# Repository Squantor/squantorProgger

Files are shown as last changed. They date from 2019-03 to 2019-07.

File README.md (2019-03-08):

# SquantProgger JTAG/SWD probe
This repository contains hardware and software for the development of the Squantprogger JTAG/SWD probe.
## What? Another programmer?
Why yes! I was not completely satisfied with the existing solutions. The two leading open source solutions like the [black magic probe](https://github.com/blacksphere/blackmagic/wiki) or the [Cortexprog](https://cortexprog.com/) have a few, in my opinion, flaws that squantProgger tries to overcome. The blackmagic probe requires a new firmware to support new devices, interface clocking is fixed speed, using the GDB interface is not entirely optimal with respect to speedups and error robustness. The Cortexprog uses bitbanged USB HID interface and is SWD only.

I really wanted to combine the strongest features of these two programmers into one package. Device support depends on the PC side software and not the probe, support SWD and JTAG at any reasonable speed (1kHz to 10MHz), be reasonably fast, no or minimal driver installation requirements.
# Repository structure
* hardware: contains the hardware of the various programmer iterations and possible extension boards
* software_embedded: contains the probe software
* software_pc: contains the PC side software
# usage
Check out using ```git clone --recurse-submodules``` as this project uses git submodules for hardware and software components.

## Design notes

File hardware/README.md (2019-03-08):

# SquantProgger hardware
There are a bunch of hardware iterations of the SquantProgger.
## SquantProgger 0.1
This programmer is the initial pilot of exploring how to create a debug probe from scratch.

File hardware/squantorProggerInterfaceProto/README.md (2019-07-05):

# Prototype for SWD/JTAG logic interface
Prototype level shifting interface for a JTAG/SWD. Operational voltage range is from 5.5V to 1.65V. The TMS switch is handled by a bus switch instead of a dual voltage level shifter. This is to prevent input/output switching on the microcontroller. This way you can more easely chain SPI transactions while using SPI chip enable pins to enable the bus
## TODO's
Still some things need to be done:
* schematic entry (Done)
* PCB layout (Done)
* Review with one night in between (Done)
* Produce at [OSHPARK](https://oshpark.com/shared_projects/nZVJTeq3) (In progress)
* Assemble (TODO)
* Test & characterise (TODO)
# BOM
Use whatever decoupling capacitors you have, most passives are predominantly 0402.
* Most 0402 capacitors for decoupling are 100nF, but 1uF is also suitable
* Series resistor R1, R2 1K can be used, the parallel caps are 22pF. These are to test if any current backflow will occur when the 1G125 is unpowered.
* U1, U2, U3 and U4 are [Diodes Incorporated 74LVC1T45DW-7 from LCSC](https://lcsc.com/product-detail/Interface-ICs_DIODES_74LVC1T45DW-7_74LVC1T45DW-7_C168855.html).
* U5 is a [Nexperia 74LVC1G125GW,125 from LCSC](https://lcsc.com/product-detail/74-Series_NXP_74LVC1G125GW_74LVC1G125GW-125_C12519.html)

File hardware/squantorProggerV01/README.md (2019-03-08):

# SquantorProgger JTAG/SWD probe version 0.1
This is the initial hardware creation of the SquantorProgger hardware to do some design exploration and figure out how to build a JTAG/SWD probe from scratch.
## Hardware architecture
The SquantProgger talks to the host system via the [CH340E](http://wch.cn/downloads/CH340DS1_PDF.html) USB to serial converter to the microcontroller [LPC824](https://www.nxp.com/products/processors-and-microcontrollers/arm-based-processors-and-mcus/lpc-cortex-m-mcus/lpc800-series-cortex-m0-plus-mcus/low-cost-microcontroll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), communication occurs at a baud rate of 1Mbaud. The CH340E also provides a reset signal via the flow control pins to reset the LPC824 and access the bootloader. The LPC824 contains the software to translate protocol calls into JTAG/SWD communication. A single output driver (74X1G125 logic chip) provides disabling of the TMS driver. The voltage level of the signals is fixed at 3.3V. The power is provided by a MCP1702 LDO. A dual P channel mosfet facilitates power switching to the target.
## HSI (Hardware Software Interface)
Description of the various connections on software programmable components.
### LPC824
### CH340E
## TODO's
Still some things need to be done:
* filling initial functions in the HSI (TODO)
* schematic entry (TODO)
* PCB layout (TODO)
* Review with one night in between (TODO)
* Produce at [OSHPARK](https://oshpark.com/) (TODO)
* Assemble (TODO)
* Test & characterise (TODO)
* update Readme.md with pictures and BOM (TODO)

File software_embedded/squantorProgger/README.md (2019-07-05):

# Squantor Programmer Probe Software
This software project contains the code for the Squantor programmer probe.
## Checking out
use ```git clone --recurse-submodules https://github.com/Squantor/squantorProgger.git``` to clone the repo and its submodules.
## Compiling
This project uses gnu make as its build system on a Linux platform. There are two build targets: release and debug. Release builds with optimizations and minimal debugging information. Debug builds with no optimization and full debug information.
```
$ make debug
$ make release
```
### Embedded targets
For debugging on embedded targets, the [Black Magic Probe](https://github.com/blacksphere/blackmagic/wiki) is used, scripts to use this debugger are present in the ```gdb_scripts``` directory. make can be used to invoke debugging:
```
make gdbusbdebug
make gdbusbrelease
```
This will build, if needed, the debug or release build respectivly and load it into the target.
```
make tpwrdisable
make tpwrenable
```
The black magic probe is capable of powering the target, these commands enable/disable this function.
### Depedencies
This program depends on a few libraries:
* [minimal LibC](https://github.com/Squantor/squantorLibC.git)
* [various embedded functions](https://github.com/Squantor/squantorLibEmbeddedC.git)
* [LPCOpen for LPC824](https://github.com/Squantor/lpc_chip_82x.git)
These are automatically checked out when using ```git clone --recurse-submodules```.
## Usage
To use the software you need the following hardware:
* [Black magic probe](https://github.com/blacksphere/blackmagic)
* $(HARDWARE)
# Hardware Software Interface (HSI)
Here is a list of signals/connections on how the probe is built up.
* Pin 12: GPIO 26: UART0 RX connection to UART TX of USB to serial converter, input
* Pin 11: GPIO 27: UART0 TX connection to UART RX of USB to serial converter, output
* Pin 13: GPIO 25: SPI0 SCK connection to JTAG TCK of the level shifter circuit, output
* Pin 14: GPIO 24: SPI0 MISO connection to JTAG TMSI of the level shifter circuit, input
* Pin 15: GPIO 15: SPI0 MOSI connection to JTAG TMSO of the level shifter circuit, output
* Pin 10: GPIO 16: SPI0 CE0 connection to JTAG TMSOE of the level shifter circuit, output
## Level shifter circuit
Descriptions of pins:
* SCK, JTAG SCK pin, level shifted via one 1T45 gate
* TMSI, input translated TMS pin, levelshifted via one 1T45 gate
* TMSO, output translated TMS pin, level shifted via 1G125
* TMSOE, output enable for the 1G125 that controls output of the TMS pin
# Additional information
If the project needs further explanation like commands, theory of operation or something else, Describe it here.
# TODO
The following tasks are still open:

* etc
# Pictures
Some pictures of a hardware project

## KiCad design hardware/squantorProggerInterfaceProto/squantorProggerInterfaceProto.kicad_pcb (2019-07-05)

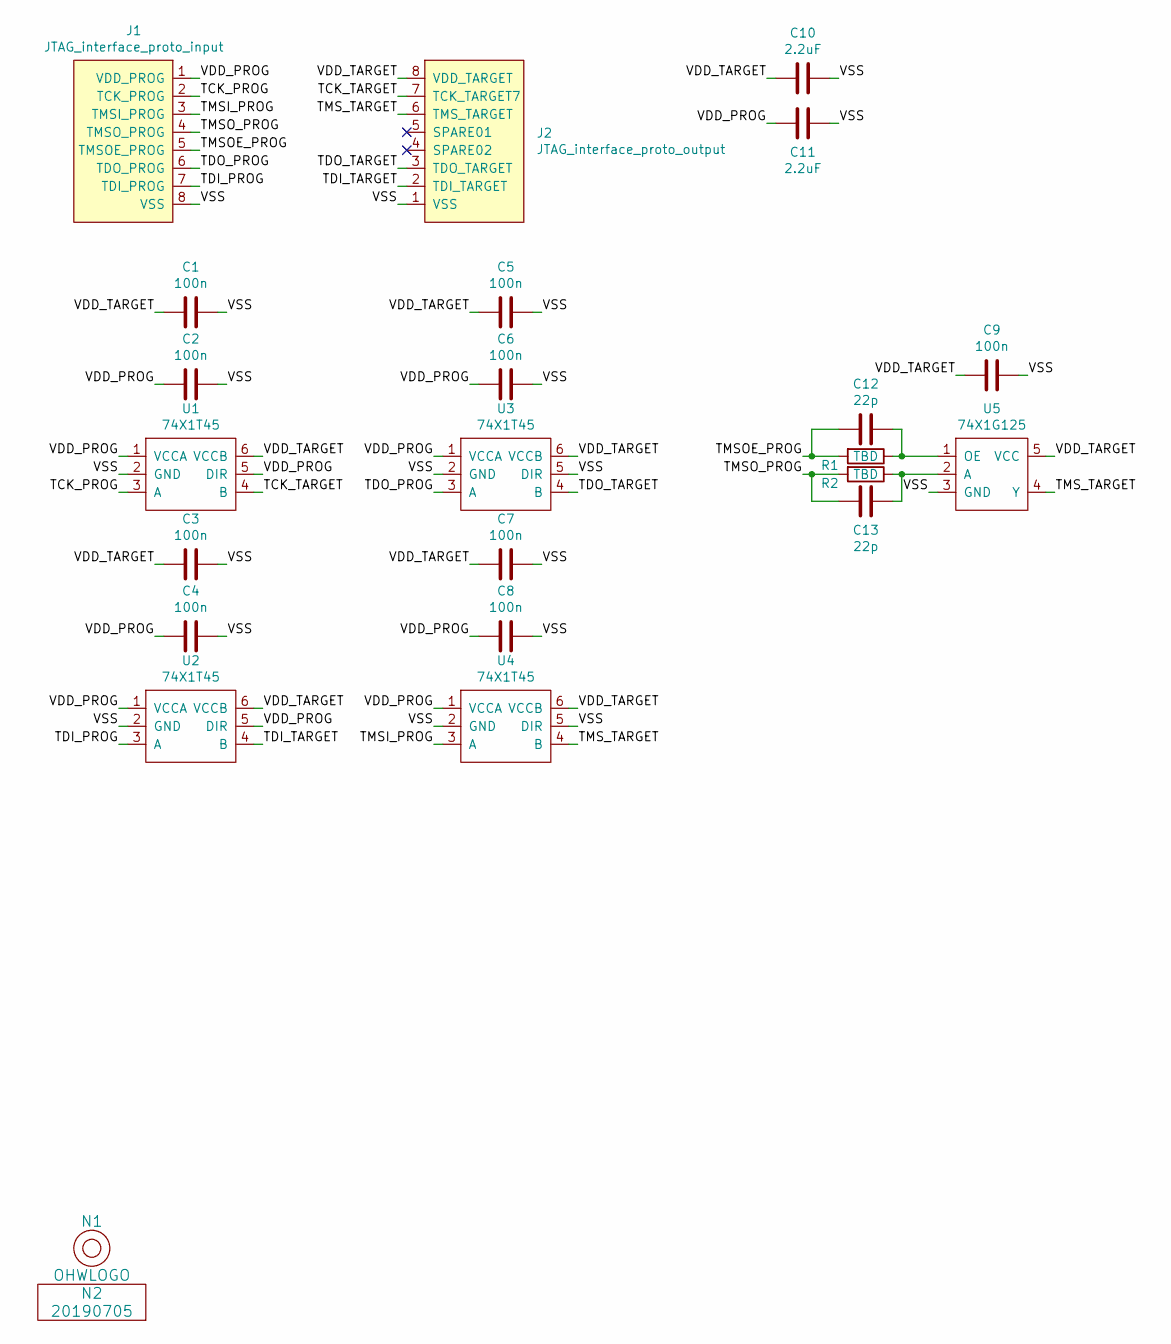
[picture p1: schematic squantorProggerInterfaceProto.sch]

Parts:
C1, C2, C3, C4, C5, C6, C7, C8, C9: 100n; C_0402
C10, C11: 2.2uF; C_0805
C12, C13: 22p; C_0402
J1: JTAG_interface_proto_input; JTAG-interface-proto-input
J2: JTAG_interface_proto_output; JTAG-interface-proto-output
N1: OHWLOGO; OSHW-Logo_5.7x6mm_SilkScreen
N2: 20190705; Label_version
R1, R2: TBD; R_0402_hand
U1, U2, U3, U4: 74X1T45; SOT363-hand
U5: 74X1G125; SOT353-hand

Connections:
/TCK_PROG: J1.2 (TCK_PROG), U1.3 (A)
/TCK_TARGET: J2.7 (TCK_TARGET7), U1.4 (B)
/TDI_PROG: J1.7 (TDI_PROG), U2.3 (A)
/TDI_TARGET: J2.2 (TDI_TARGET), U2.4 (B)
/TDO_PROG: J1.6 (TDO_PROG), U3.3 (A)
/TDO_TARGET: J2.3 (TDO_TARGET), U3.4 (B)
/TMSI_PROG: J1.3 (TMSI_PROG), U4.3 (A)
/TMSOE_PROG: C12.2, J1.5 (TMSOE_PROG), R1.2
/TMSO_PROG: C13.2, J1.4 (TMSO_PROG), R2.2
/TMS_TARGET: J2.6 (TMS_TARGET), U4.4 (B), U5.4 (Y)
/VDD_PROG: C2.2, C4.2, C6.2, C8.2, C11.2, J1.1 (VDD_PROG), U1.1 (VCCA), U1.5 (DIR), U2.1 (VCCA), U2.5 (DIR), U3.1 (VCCA), U4.1 (VCCA)
/VDD_TARGET: C1.2, C3.2, C5.2, C7.2, C9.2, C10.2, J2.8 (VDD_TARGET), U1.6 (VCCB), U2.6 (VCCB), U3.6 (VCCB), U4.6 (VCCB), U5.5 (VCC)
/VSS: C1.1, C2.1, C3.1, C4.1, C5.1, C6.1, C7.1, C8.1, C9.1, C10.1, C11.1, J1.8 (VSS), J2.1 (VSS), U1.2 (GND), U2.2 (GND), U3.2 (GND), U3.5 (DIR), U4.2 (GND), U4.5 (DIR), U5.3 (GND)
unnamed: C12.1, R1.1, U5.1 (OE)
unnamed: C13.1, R2.1, U5.2 (A)

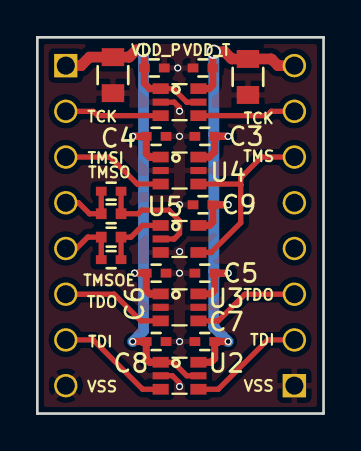
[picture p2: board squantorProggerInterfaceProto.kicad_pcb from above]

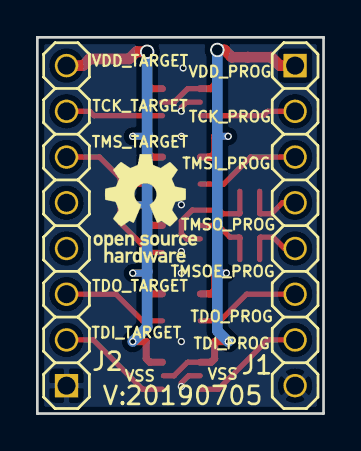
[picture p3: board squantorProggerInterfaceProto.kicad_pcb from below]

Board: 2 copper layers, 15.9 x 20.9 mm, 24 parts (4 on the bottom side), 15 nets.

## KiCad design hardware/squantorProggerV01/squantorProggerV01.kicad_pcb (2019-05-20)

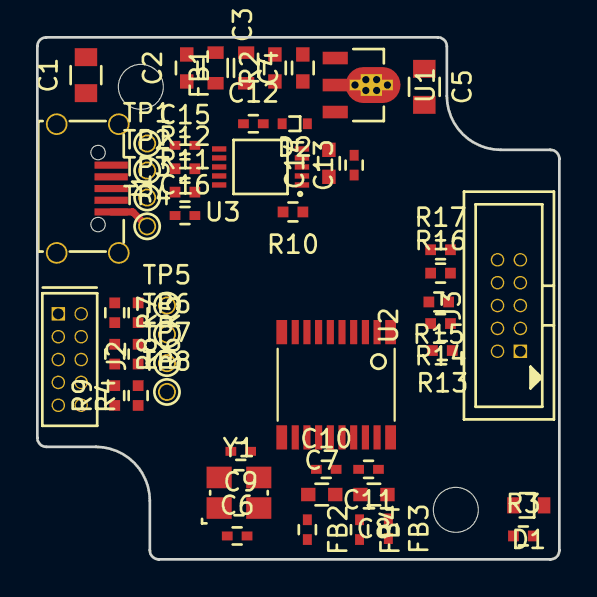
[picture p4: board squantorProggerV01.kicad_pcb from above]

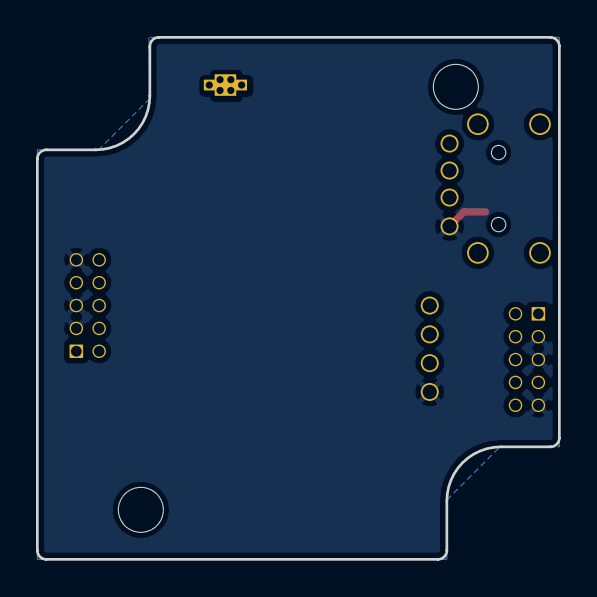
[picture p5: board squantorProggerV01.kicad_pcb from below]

Board: 2 copper layers, 29.0 x 29.0 mm, 57 parts (2 on the bottom side), 29 nets.

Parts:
C1: 100n; C_0805
C2: 100n; C_0603
C3, C4, C7, C8, C14: 1u; C_0603
C5: 10u; C_0805
C6, C9: 18p; C_0402
C10, C11, C12, C13: 100n; C_0402
C15, C16: 47p; C_0402
D1: RED; D_0603_hand
D2: D; SOD-523
FB1: 600; R_0603_hand
FB2, FB3, FB4: FB; C_0402
H1, H2: Drill_Hole_no_metal; MountingHole_2.5mm_no_metal
J1: USB-ID; USB-muB-SMD_TH
J2: JTAG_2X05; Header-0127-2X05-H006
J3: JTAG_2X05_OUT; Header-Shr-0127-2X05-H006
N1: OHWLOGO; OSHW-Symbol_6.7x6mm_SilkScreen
N2: 20190520; Label_version
R2: Fuse; R_0603_hand
R3: 1K; R_0402_hand
R4: 100K; R_0402_hand
R5, R6: 100k; R_0402_hand
R7, R8, R9, R13, R14, R15, R16, R17: 100; R_0402_hand
R10: 10K; R_0402_hand
R11, R12: 33; R_0402_hand
TP1, TP2, TP3, TP4, TP5, TP6, TP7, TP8: testpad; TestPoint_Hole_D0.8mm
U1: MCP1702-MB; SOT89-ViaTab-Microchip-MB
U2: LPC824M201JDH20; SOT360
U3: HT42B534-MSOP10; MSOP-10
Y1: 12MHz; Crystal_3225_4

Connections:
/HT42B534 application example/V33O: C14.1, U3.2
/PIO0_2: R5.2, R7.2, TP5.1, U2.8
/PIO0_3: R6.2, R8.2, TP6.1, U2.7
/PIO0_8: C9.1, U2.14, Y1.3
/PIO0_9: C6.1, U2.13, Y1.1
/RESET: R4.2, R9.2, TP7.1, U2.5
/TXO: R10.1, U3.5
/USB_D+: J1.3, R11.1, TP3.1
/USB_D-: J1.2, R12.1, TP2.1
/VBUS: C2.1, J1.1, R2.2, TP1.1
/VBUS_FILT: C3.1, C13.1, D2.1, FB1.1, U1.2, U1.TAB, U3.1
/VDD: C4.1, C5.2, C12.1, D2.2, FB2.2, FB3.2, J2.1, R3.2, R4.1, R5.1, R10.2, U1.3, U3.6
unnamed: C1.1, J1.S
unnamed: C7.1, C10.1, FB2.1, U2.15
unnamed: C8.1, C11.1, FB3.1, U2.18
unnamed: C8.2, C11.2, FB4.1, U2.17
unnamed: C15.2, R12.2, U3.9
unnamed: C16.2, R11.2, U3.10
unnamed: D1.2, R3.1
unnamed: FB1.2, R2.1
unnamed: J2.2, R7.1
unnamed: J2.4, R8.1
unnamed: J2.10, R9.1
unnamed: J3.2, R13.1
unnamed: J3.4, R14.1
unnamed: J3.6, R15.1
unnamed: J3.8, R16.1
unnamed: J3.10, R17.1
VSS: C1.2, C2.2, C3.2, C4.2, C5.1, C6.2, C7.2, C9.2, C10.2, C12.2, C13.2, C14.2, C15.1, C16.1, D1.1, FB4.2, J1.5, J2.3, J2.5, J2.9, J3.3, J3.5, J3.9, R6.1, TP4.1, TP8.1, U1.1, U2.16, U3.3, Y1.2, Y1.4

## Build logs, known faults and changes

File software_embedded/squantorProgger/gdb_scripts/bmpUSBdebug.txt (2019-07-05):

file bin/debug/squantorProgger.elf
target extended-remote /dev/ttyBmpGdb0
monitor tpwr enable
shell sleep 1
monitor swdp_scan
attach 1
set mem inaccessible-by-default off
set {int}0x40048000 = 2
load bin/debug/squantorProgger.elf
set {int}0x40048000 = 2
compare-sections
b main

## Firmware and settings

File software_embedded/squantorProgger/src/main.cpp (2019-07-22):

/*
MIT License

Copyright (c) 2019 Bart Bilos

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
THE SOFTWARE IS PROVIDED "AS IS", WITHOUT WARRANTY OF ANY KIND, EXPRESS OR
IMPLIED, INCLUDING BUT NOT LIMITED TO THE WARRANTIES OF MERCHANTABILITY,
FITNESS FOR A PARTICULAR PURPOSE AND NONINFRINGEMENT. IN NO EVENT SHALL THE
AUTHORS OR COPYRIGHT HOLDERS BE LIABLE FOR ANY CLAIM, DAMAGES OR OTHER
LIABILITY, WHETHER IN AN ACTION OF CONTRACT, TORT OR OTHERWISE, ARISING FROM,
OUT OF OR IN CONNECTION WITH THE SOFTWARE OR THE USE OR OTHER DEALINGS IN THE
SOFTWARE.
*/
/*
Main entry file
*/
#include <stdint.h>
#include <board.hpp>
#include <stream_uart.hpp>
#include <strings.hpp>
#include <chip.h>
#include <prompt_mini.h>
#include <commands.hpp>
#include <systick.hpp>


char promptBuf[16];
result cmdlineParse(char *cmdline);

promptData_t sqProgPromptData = 
{
    promptBuf,
    0,
    sizeof(promptBuf),
    cmdlineParse,
};

result cmdlineParse(char *const cmdline)
{
    return commandInterpret(sqProgCommands, cmdline);
}

int main()
{
    boardInit();
    dsPuts(&streamUart, strHello);
    while (1) {
        promptProcess(&sqProgPromptData, &streamUart);
    }
}

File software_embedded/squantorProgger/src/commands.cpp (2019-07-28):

/*
MIT License

Copyright (c) 2019 Bart Bilos

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
THE SOFTWARE IS PROVIDED "AS IS", WITHOUT WARRANTY OF ANY KIND, EXPRESS OR
IMPLIED, INCLUDING BUT NOT LIMITED TO THE WARRANTIES OF MERCHANTABILITY,
FITNESS FOR A PARTICULAR PURPOSE AND NONINFRINGEMENT. IN NO EVENT SHALL THE
AUTHORS OR COPYRIGHT HOLDERS BE LIABLE FOR ANY CLAIM, DAMAGES OR OTHER
LIABILITY, WHETHER IN AN ACTION OF CONTRACT, TORT OR OTHERWISE, ARISING FROM,
OUT OF OR IN CONNECTION WITH THE SOFTWARE OR THE USE OR OTHER DEALINGS IN THE
SOFTWARE.
*/
#include <command_mini.h>
#include <stddef.h>
#include <board.hpp>
#include <chip.h>
#include <stream_uart.hpp>
#include <strings.hpp>
#include <parsedigit.h>
#include <string.h>
#include <print.h>

result cmdPrintVerHandler(const char *argument);
result cmdSpiTestHandler(const char *argument);
result cmdSwdEnableHandler(const char *argument);
result cmdSwdDisableHandler(const char *argument);
result cmdGeneralTestHandler(const char *argument);

const char cmdPrintVer[] = "pv";
const char cmdSpiTest[] = "ts";
const char cmdSwdEnable[] = "swde";
const char cmdSwdDisable[] = "swdd";
const char cmdGeneralTest[] = "test";


commandEntry_t sqProgCommands[] = 
{
    {cmdPrintVer, cmdPrintVerHandler},
    {cmdSpiTest, cmdSpiTestHandler},
    {cmdSwdEnable, cmdSwdEnableHandler},
    {cmdSwdDisable, cmdSwdDisableHandler},
    {cmdGeneralTest, cmdGeneralTestHandler},
    {NULL, NULL},
};

// commands may not use an argument and this is fine, ignore warning
#pragma GCC diagnostic ignored "-Wunused-parameter"
result cmdPrintVerHandler(const char *argument)
{
    dsPuts(&streamUart, strHello);
    return noError;
}

result cmdGeneralTestHandler(const char *argument)
{
    Chip_GPIO_SetPinDIROutput(LPC_GPIO_PORT, 0, JTAG_TCK_GPIO);
    Chip_GPIO_SetPinToggle(LPC_GPIO_PORT, 0, JTAG_TCK_GPIO);
}

// now we want warnings on arguments missing again
#pragma GCC diagnostic pop


result cmdSpiTestHandler(const char *argument)
{
    const char *s = argument;
    unsigned int bitCount;
    
    if(parseDigit(*s, &bitCount) != parseOk)
        return invalidArg;
    s++;
    // we know bit count, now check rest
    unsigned int charCount = (bitCount / 4 + 1);
    if(strlen(s) != charCount)
        return invalidArg;
    // we increment bit count so we cover a range from 1 to 16
    bitCount++;
    // parse data characters
    uint16_t spiData = 0;
    for(unsigned int i = 0; i < charCount; i++)
    {
        spiData = spiData << 4;
        unsigned int data;
        if(parseDigit(*s, &data) != parseOk)
            return invalidArg;
        s++;
        spiData = spiData | (uint16_t) data;
    }
    // transfer
    uint32_t transfer = spiData | 
    (0xE << 16) |
    SPI_TXDATCTL_EOT |
    SPI_TXDATCTL_FLEN(bitCount-1);
    Chip_SPI_ClearStatus(LPC_SPI0, SPI_STAT_CLR_RXOV | SPI_STAT_CLR_TXUR | SPI_STAT_CLR_SSA | SPI_STAT_CLR_SSD);
    while( !(Chip_SPI_GetStatus(LPC_SPI0) & SPI_STAT_TXRDY)) 
        ;
    LPC_SPI0->TXDATCTL = transfer;
    while( !(Chip_SPI_GetStatus(LPC_SPI0) & SPI_STAT_RXRDY)) 
        ;
    uint16_t rxData = (uint16_t) LPC_SPI0->RXDAT & 0xFFFF;
    printHexU32(&streamUart, rxData);
    dsPuts(&streamUart, strNl);    
    // print result
    return noError;
}

result cmdSwdEnableHandler(const char *argument)
{
    // check if we have valid divisor number, max 4 hex digits
    size_t arglen = strlen(argument);
    if((arglen == 0) || (arglen > 4))
        return invalidArg;
    uint16_t divisor = 0;
    for(unsigned int i = 0; i < arglen; i++)
    {
        divisor = divisor << 4;
        unsigned int data;
        if(parseDigit(*argument, &data) != parseOk)
            return invalidArg;
        argument++;
        divisor = divisor | (uint16_t) data;
    }    
    Chip_Clock_EnablePeriphClock(SYSCTL_CLOCK_SWM);
    Chip_SWM_MovablePinAssign(SWM_SPI0_SCK_IO, JTAG_TCK_GPIO);
    Chip_SWM_MovablePinAssign(SWM_SPI0_MISO_IO, JTAG_TMSI_GPIO);
    Chip_SWM_MovablePinAssign(SWM_SPI0_MOSI_IO, JTAG_TMSO_GPIO);
    Chip_SWM_MovablePinAssign(SWM_SPI0_SSEL0_IO, JTAG_TMSOE_GPIO);
    Chip_Clock_DisablePeriphClock(SYSCTL_CLOCK_SWM);
    Chip_Clock_EnablePeriphClock(SYSCTL_CLOCK_SPI0);
    Chip_SYSCTL_PeriphReset(RESET_SPI0);
    Chip_SPI_ConfigureSPI(LPC_SPI0, SPI_CFG_MASTER_EN |
                                    SPI_CLOCK_CPHA0_CPOL0 |
                                    SPI_CFG_MSB_FIRST_EN |
                                    SPI_CFG_SPOL_LO);
    LPC_SPI0->DLY = 0x0;
    LPC_SPI0->DIV = SPI_DIV_VAL(divisor);
    Chip_SPI_Enable(LPC_SPI0);
    return noError;
}

result cmdSwdDisableHandler(const char *argument)
{
    Chip_Clock_DisablePeriphClock(SYSCTL_CLOCK_SPI0);
    // reset SPI core
    return noError;
}

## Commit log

2019-03-08 added squantorProggerV01 hardware project based on kicad template for the Hammond 1551M project box, 2 layer OSHpark
    [squantorProggerV01.kicad_pcb, squantorProggerV01.sch]
2019-03-08 placed connectors
    [squantorProggerV01.kicad_pcb, squantorProggerV01.sch]
2019-03-08 ignoring more kicad intermediates
2019-03-08 small update
    [squantorProggerV01.kicad_pcb]
2019-03-09 newer Pcb library, started usb serial bits
    [squantorProggerV01.sch]
2019-04-02 newer kicad libraries
2019-04-02 cleanup of obsolete parts
    [squantorProggerV01.sch]
2019-04-02 imported schematics of LPC824 breakout and HT42B534 breakout
    [squantorProggerV01.kicad_pcb, squantorProggerV01.sch]
2019-04-06 added HT42B534 application schematic
    [HT42B534_application.sch]
2019-04-06 added test points to USB and SWD in
    [HT42B534_application.sch, squantorProggerV01.kicad_pcb, squantorProggerV01.sch]
2019-05-20 updated footprint
    [squantorProggerV01.kicad_pcb, squantorProggerV01.sch]
2019-07-02 newer pcb library
2019-07-02 added prototype JTAG/SWD interface
    [squantorProggerInterfaceProto.kicad_pcb, squantorProggerInterfaceProto.sch]
2019-07-02 added named connectors from library
2019-07-02 completed schematic, passes DRC
    [squantorProggerInterfaceProto.sch]
2019-07-03 added newer library adding SOT353 footprints
2019-07-03 added rail decoupling
    [squantorProggerInterfaceProto.sch]
2019-07-03 footprints defined for level shifter IC's
    [squantorProggerInterfaceProto.sch]
2019-07-03 initial placement of components
    [squantorProggerInterfaceProto.kicad_pcb, squantorProggerInterfaceProto.sch]
2019-07-04 added named connectors to schematic, moved silk
    [squantorProggerInterfaceProto.kicad_pcb]
2019-07-04 routing completed, no DRC errors
    [squantorProggerInterfaceProto.kicad_pcb]
2019-07-04 front silk nicely placed
    [squantorProggerInterfaceProto.kicad_pcb]
2019-07-04 bottom silk placed
    [squantorProggerInterfaceProto.kicad_pcb]
2019-07-04 changed OSH logo, front silk mistake fixed
    [squantorProggerInterfaceProto.kicad_pcb, squantorProggerInterfaceProto.sch]
2019-07-05 final checks, in production
    [squantorProggerInterfaceProto.kicad_pcb, squantorProggerInterfaceProto.sch]
2019-07-05 updated Readme for JTAG interface prototype board
2019-07-05 copied over basic uart init
2019-07-05 UART output functional
2019-07-05 added initial SPI initialization
2019-07-05 initial start on SPI driver
2019-07-05 added TODOs for SPI driver
2019-07-22 removing alive message printing
2019-07-22 WIP: adding spi test command to prompt
2019-07-24 completed spi test command parsing
2019-07-27 added SWD pins control to board HAL
2019-07-27 added pin and gpio definitions and properly initialized them
2019-07-27 fixed pin definitions, they where wrong!
    [board.hpp]
2019-07-27 finally got some SPI output
2019-07-28 fixed incorrect slave select
    [commands.cpp]
